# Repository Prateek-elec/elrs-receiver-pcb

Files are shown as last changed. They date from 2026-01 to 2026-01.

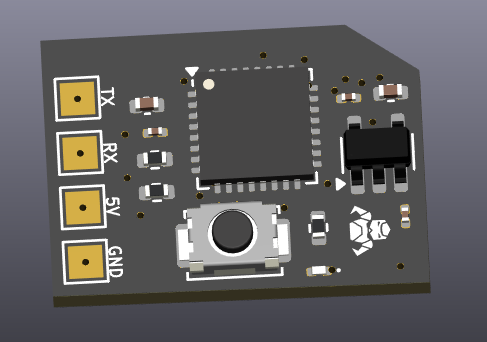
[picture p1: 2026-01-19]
docs/image/Screenshot 2026-01-19 194240.png

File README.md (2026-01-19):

# ELRS Receiver PCB (ESP8285 + SX1280) 📡

A compact **ExpressLRS (ELRS) receiver hardware design** built around **ESP8285** and the **SX1280** LoRa transceiver.
This repository contains the full **KiCad schematic and PCB layout**, along with documentation and renders.

---

## ✅ Features
- **ESP8285 MCU** (WiFi-enabled microcontroller, ELRS compatible)
- **SX1280 LoRa transceiver** for 2.4GHz ELRS
- **3.3V LDO regulation** using **MIC5219-3.3YMS**
- **Reverse polarity / input protection** using Schottky diode
- **RF output via coax / U.FL connector** support
- Status LED + reset/boot support
- Compact 2-layer PCB layout suitable for UAV / RC applications

---

## 🧩 Block Overview
### 1) MCU Section (ESP8285)
- Powered from 3.3V rail
- Boot/enable circuitry included
- UART pads/testpoints for debugging and flashing

### 2) RF Section (SX1280)
- SPI interface from ESP8285 (MISO/MOSI/SCK/CS)
- Reset and BUSY signals connected
- RF output routed to coax connector
- 52 MHz reference crystal provided

### 3) Power Section
- Input → Schottky protection → **MIC5219 3.3V LDO**
- Local decoupling capacitors placed close to ICs

---

## 📷 Project Preview
> Add your images in `docs/images/` and they will show here.

### Schematic
Schematic

### PCB Layout
PCB Layout

---

## 📂 Repository Structure
- `hardware/kicad/` → KiCad project files (`.kicad_pro`, `.kicad_sch`, `.kicad_pcb`)
- `docs/images/` → screenshots (schematic / PCB / 3D view)
- `fabrication/` → Gerbers, drill files, BOM, pick & place (optional)

---

## ✅ Getting Started (KiCad)
1. Install **KiCad 8 / KiCad 9**
2. Open the project file:
   - `hardware/kicad/elrs_receiver.kicad_pro`
3. View schematic:
   - `elrs_receiver.kicad_sch`
4. View PCB:
   - `elrs_receiver.kicad_pcb`
5. Export Gerbers (if needed):
   - PCB Editor → **File → Plot…**

---

## ⚠️ Notes / Disclaimer
This is a personal hardware project made for learning and experimentation.  
Please validate your RF layout, matching network, and manufacturing constraints before using it in real flight systems.

---

## 👤 Author
**Prateek Sarkar**  
Embedded Systems • PCB Design (KiCad) • UAV / Robotics

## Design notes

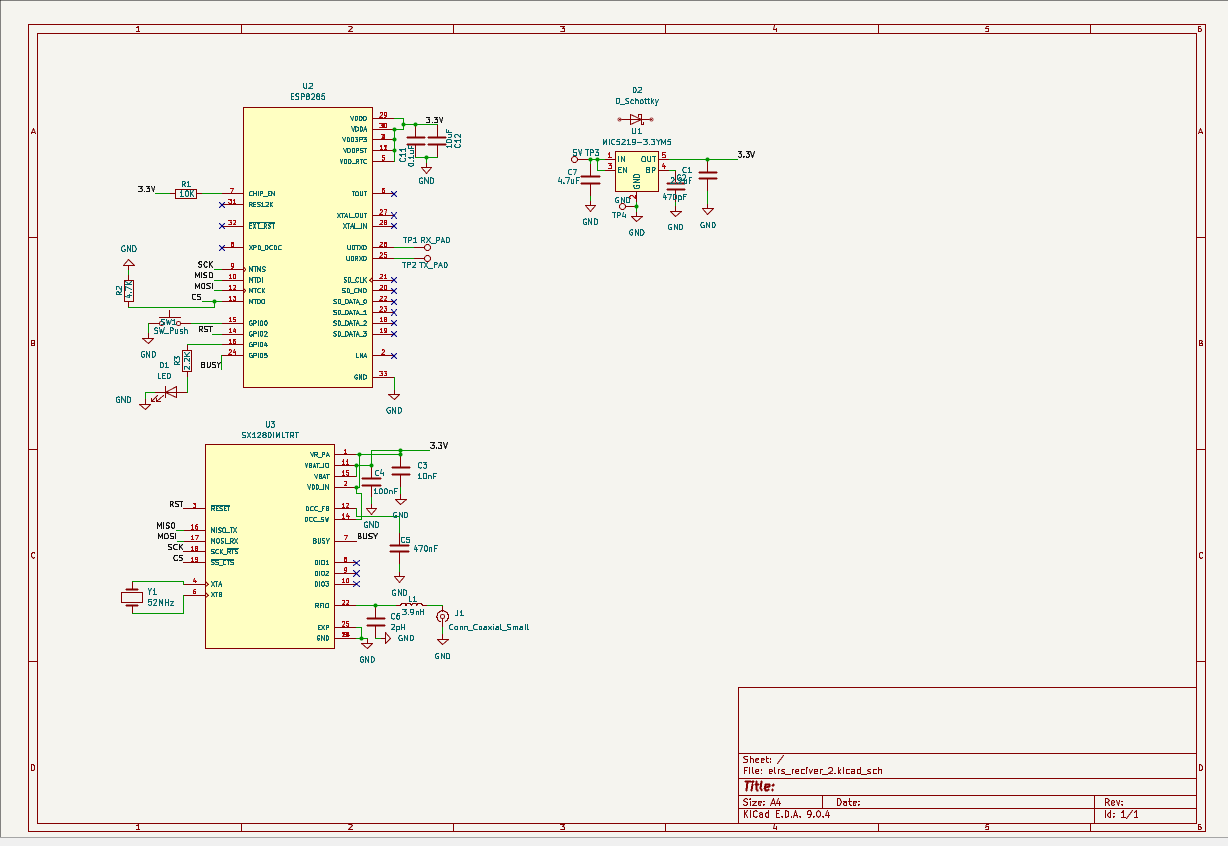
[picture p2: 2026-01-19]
docs/image/Screenshot 2026-01-19 194055.png

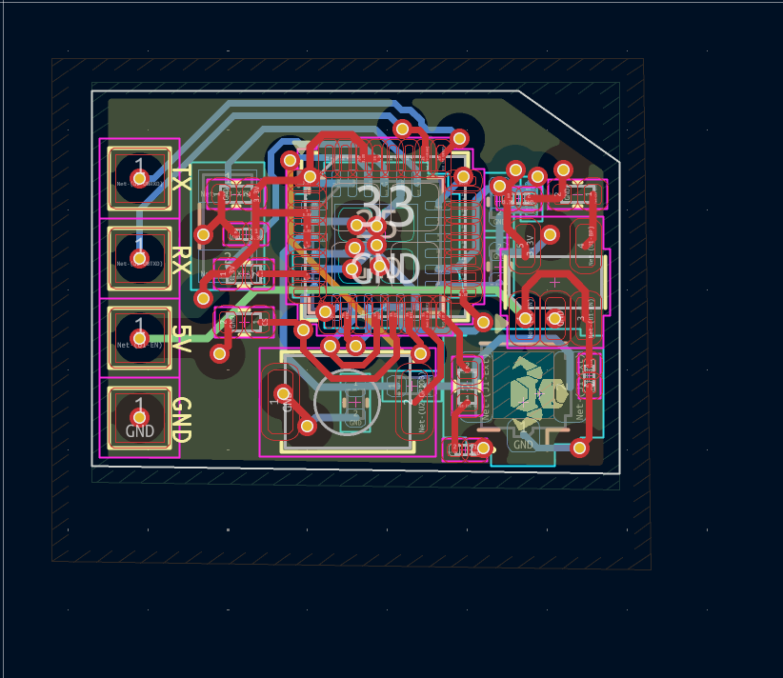
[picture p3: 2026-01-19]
docs/image/Screenshot 2026-01-19 194121.png

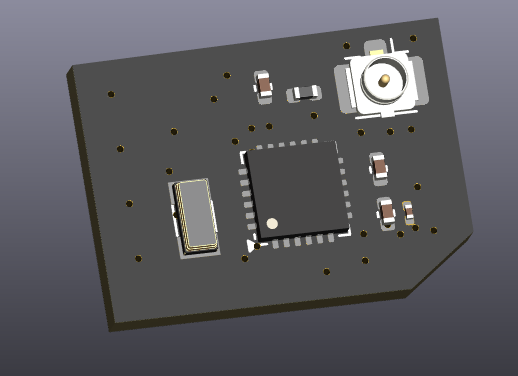
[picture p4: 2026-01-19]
docs/image/Screenshot 2026-01-19 194304.png

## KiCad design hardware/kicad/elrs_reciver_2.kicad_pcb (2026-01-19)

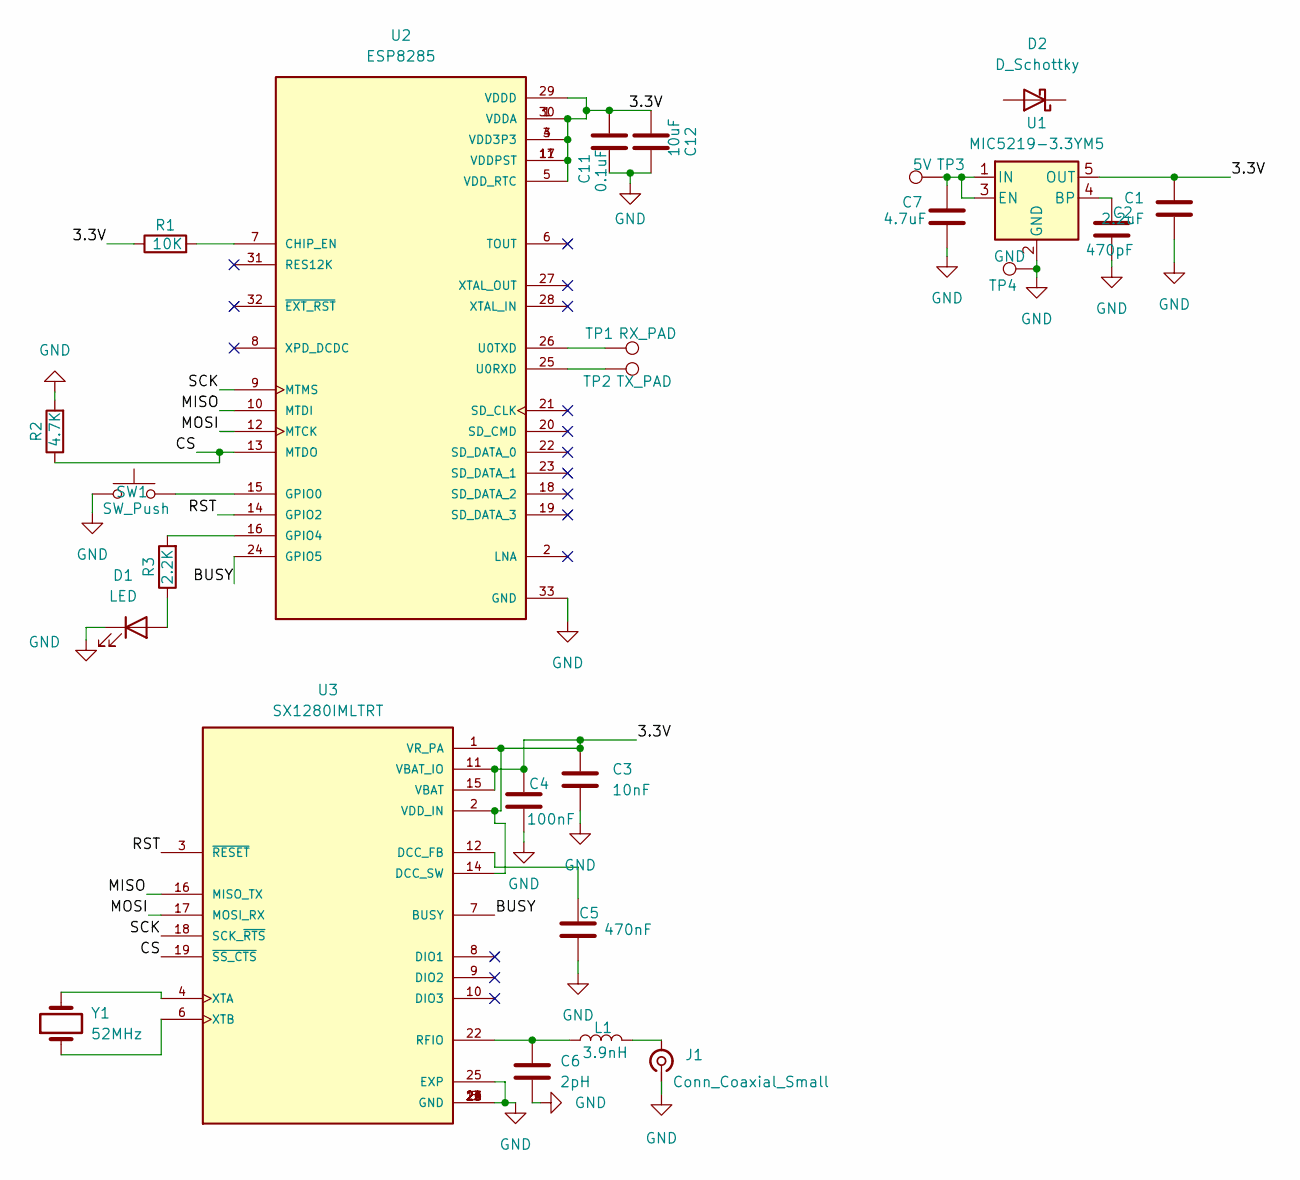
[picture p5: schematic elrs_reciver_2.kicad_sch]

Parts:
C1: 2.2uF; C_0201_0603Metric
C2: 470pF; C_0402_1005Metric
C3: 10nF; C_0402_1005Metric
C4: 100nF; C_0201_0603Metric
C5: 470nF; C_0402_1005Metric
C6: 2pH; C_0402_1005Metric
C7: 4.7uF; C_0201_0603Metric
C11: 0.1uF; C_0402_1005Metric
C12: 10uF; C_0201_0603Metric
D1: LED; LED_0201_0603Metric
D2: D_Schottky
J1: Conn_Coaxial_Small; U.FL_Hirose_U.FL-R-SMT-1_Vertical
L1: 3.9nH; L_0402_1005Metric
R1: 10K; R_0402_1005Metric
R2: 4.7K; R_0402_1005Metric
R3: 2.2K; R_0402_1005Metric
SW1: SW_Push; SW_Push_SPST_NO_Alps_SKRK
TP1: RX_PAD; TestPoint_Pad_1.5x1.5mm
TP2: TX_PAD; TestPoint_Pad_1.5x1.5mm
TP3: 5V; TestPoint_Pad_1.5x1.5mm
TP4: GND; TestPoint_Pad_1.5x1.5mm
U1: MIC5219-3.3YM5; SOT-23-5
U2: ESP8285; QFN-32-1EP_5x5mm_P0.5mm_EP3.7x3.7mm; PARTREV 2.0
U3: SX1280IMLTRT; QFN-24-1EP_4x4mm_P0.5mm_EP2.6x2.6mm; PARTREV 3.3
Y1: 52MHz; Crystal_SMD_3215-2Pin_3.2x1.5mm

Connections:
/3.3V: C1.1, C3.1, C4.1, C11.2, C12.1, R1.1, U1.5 (OUT), U2.1 (VDDA), U2.3 (VDD3P3), U2.4 (VDD3P3), U2.5 (VDD_RTC), U2.11 (VDDPST), U2.17 (VDDPST), U2.29 (VDDD), U2.30 (VDDA), U3.1 (VR_PA), U3.2 (VDD_IN), U3.11 (VBAT_IO), U3.14 (DCC_SW), U3.15 (VBAT)
/BUSY: U2.24 (GPIO5), U3.7 (BUSY)
/CS: R2.1, U2.13 (MTDO), U3.19 (~SS_CTS)
/MISO: U2.10 (MTDI), U3.16 (MISO_TX)
/MOSI: U2.12 (MTCK), U3.17 (MOSI_RX)
/RST: U2.14 (GPIO2), U3.3 (~RESET)
/SCK: U2.9 (MTMS), U3.18 (SCK_~RTS)
GND: C1.2, C2.2, C3.2, C4.2, C5.2, C6.2, C7.2, C11.1, C12.2, D1.1 (K), J1.1 (In), R2.2, SW1.1, TP4.1, U1.2 (GND), U2.33 (GND), U3.5 (GND), U3.13 (GND), U3.20 (GND), U3.21 (GND), U3.23 (GND), U3.24 (GND), U3.25 (EXP)
unnamed: D1.2 (A), R3.1
unnamed: J1.2 (Ext), L1.2
unnamed: C2.1, U1.4 (BP)
unnamed: C7.1, TP3.1, U1.1 (IN), U1.3 (EN)
unnamed: R1.2, U2.7 (CHIP_EN)
unnamed: SW1.2, U2.15 (GPIO0)
unnamed: R3.2, U2.16 (GPIO4)
unnamed: TP2.1, U2.25 (U0RXD)
unnamed: TP1.1, U2.26 (U0TXD)
unnamed: C5.1, U3.12 (DCC_FB)
unnamed: C6.1, L1.1, U3.22 (RFIO)
unnamed: U3.4 (XTA), Y1.2
unnamed: U3.6 (XTB), Y1.1

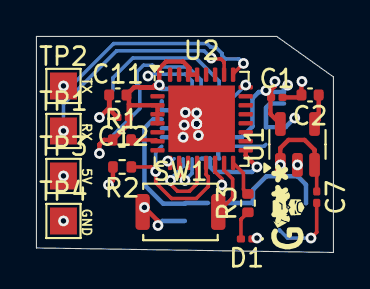
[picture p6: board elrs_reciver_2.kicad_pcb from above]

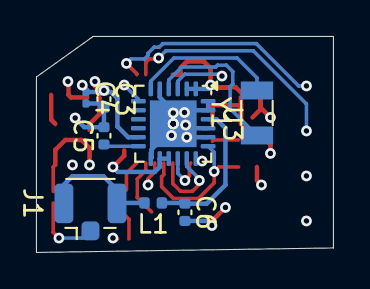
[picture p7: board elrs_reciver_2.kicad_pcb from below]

Board: 4 copper layers, 16.5 x 12.0 mm, 24 parts (8 on the bottom side), 21 nets.
